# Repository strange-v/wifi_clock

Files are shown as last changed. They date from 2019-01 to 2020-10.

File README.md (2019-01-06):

# WiFi Clock
One more WiFi clock based on DS1339U and ESP8266. Requires 12V 1.5A power source.

## Functionality
* 24 hours time format
* Automatic time sync (NTP server and interval can be configured)
* Auto brightness
* DST support
* Display options (on/off leading zero, on/off column blinking, do not blink in a specific period of time)
* Over-the-Air update

## Main components
- ESP8266 - microcontroller 
- DS1339U - real time clock
- PCA9685 x 2 - LED controller
- BH1750FVI-TR - light sensor
- MT2492 - step-down  converter
- LM1117IMP-3.3 - voltage regulator

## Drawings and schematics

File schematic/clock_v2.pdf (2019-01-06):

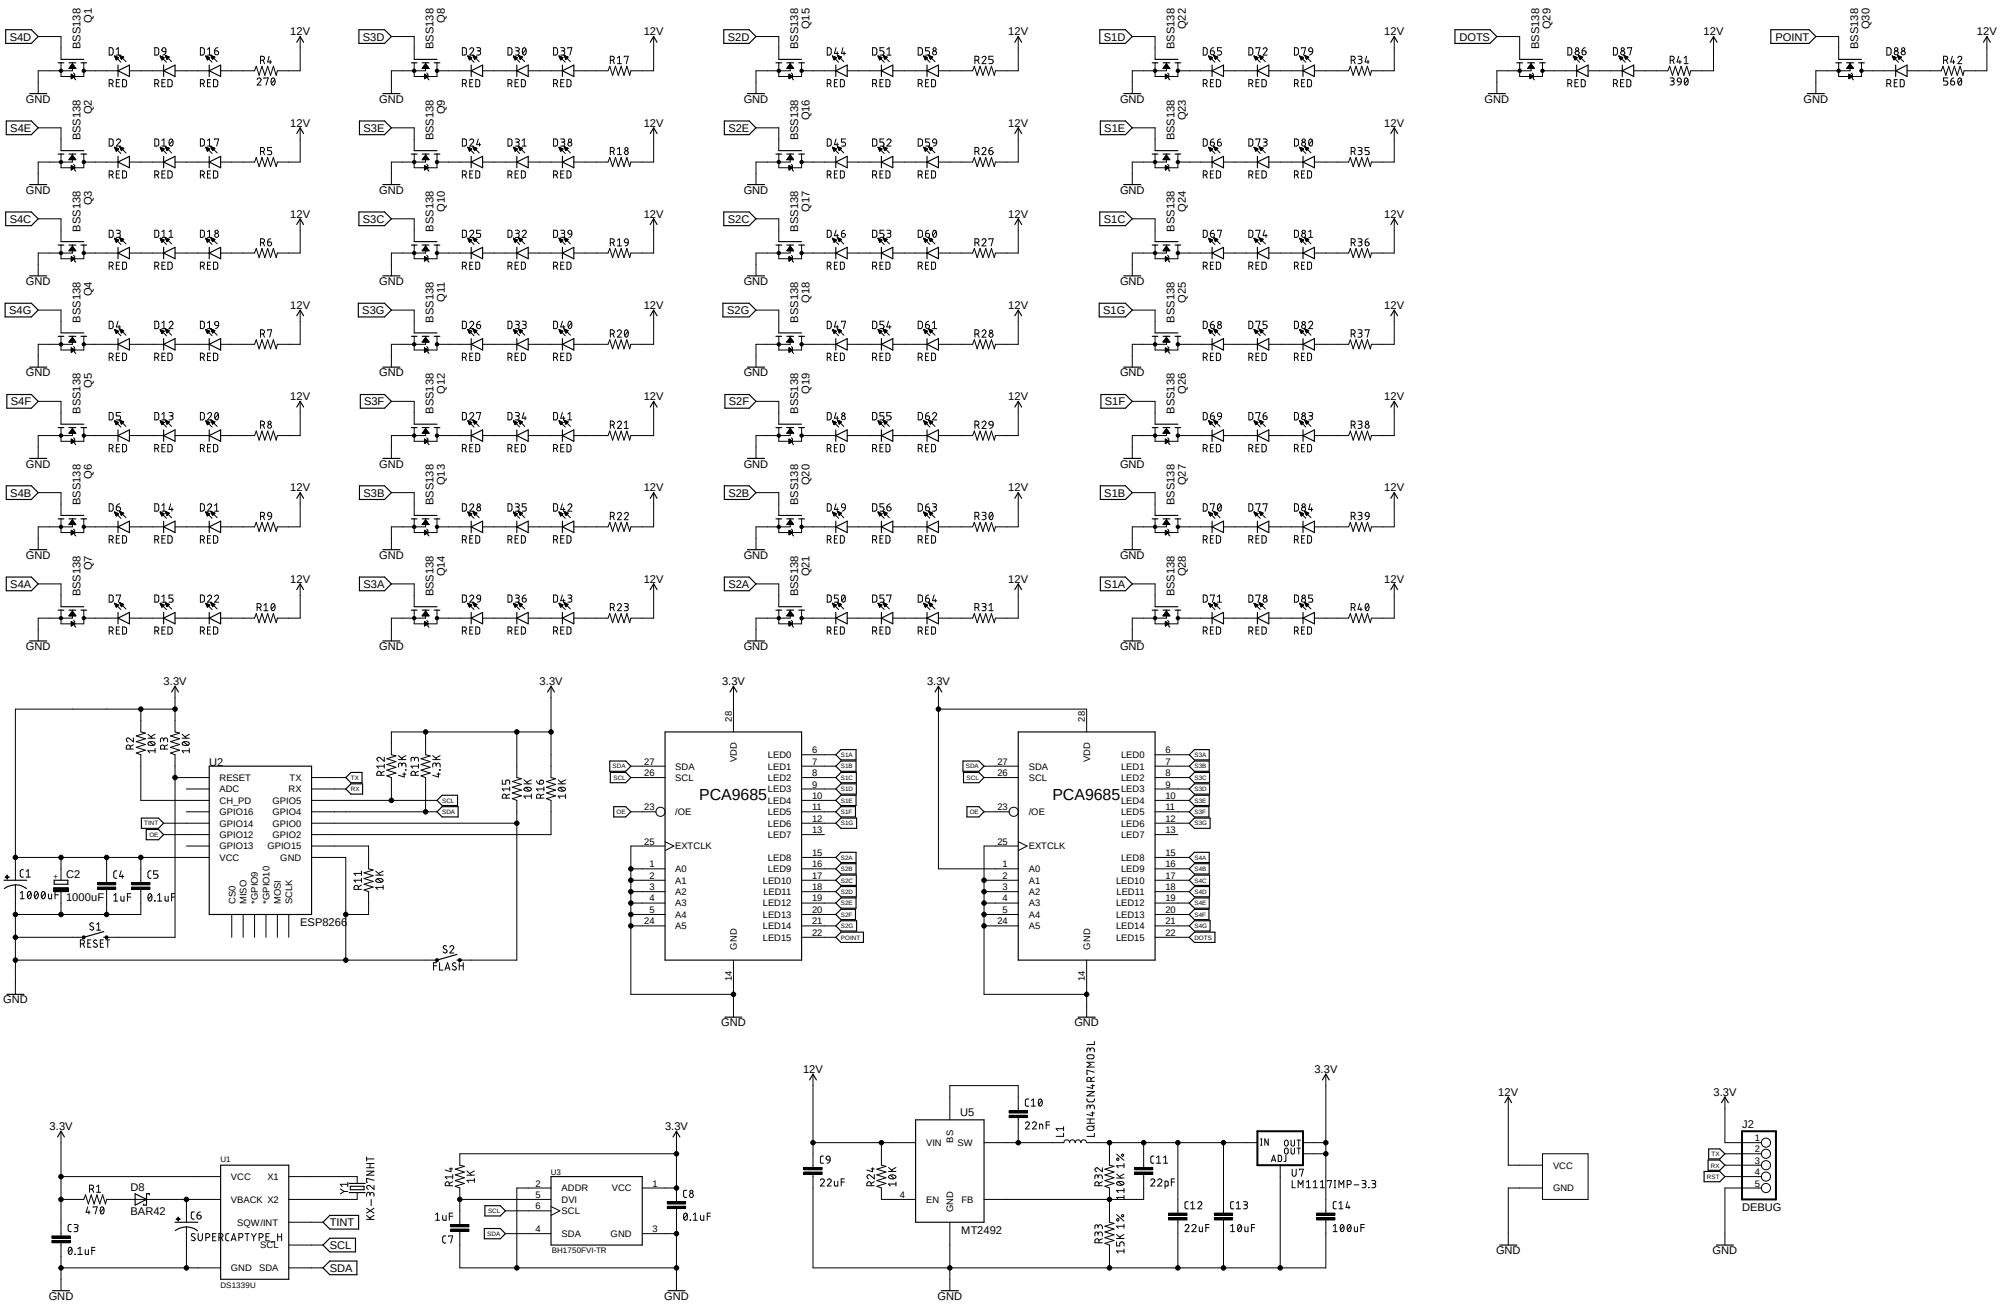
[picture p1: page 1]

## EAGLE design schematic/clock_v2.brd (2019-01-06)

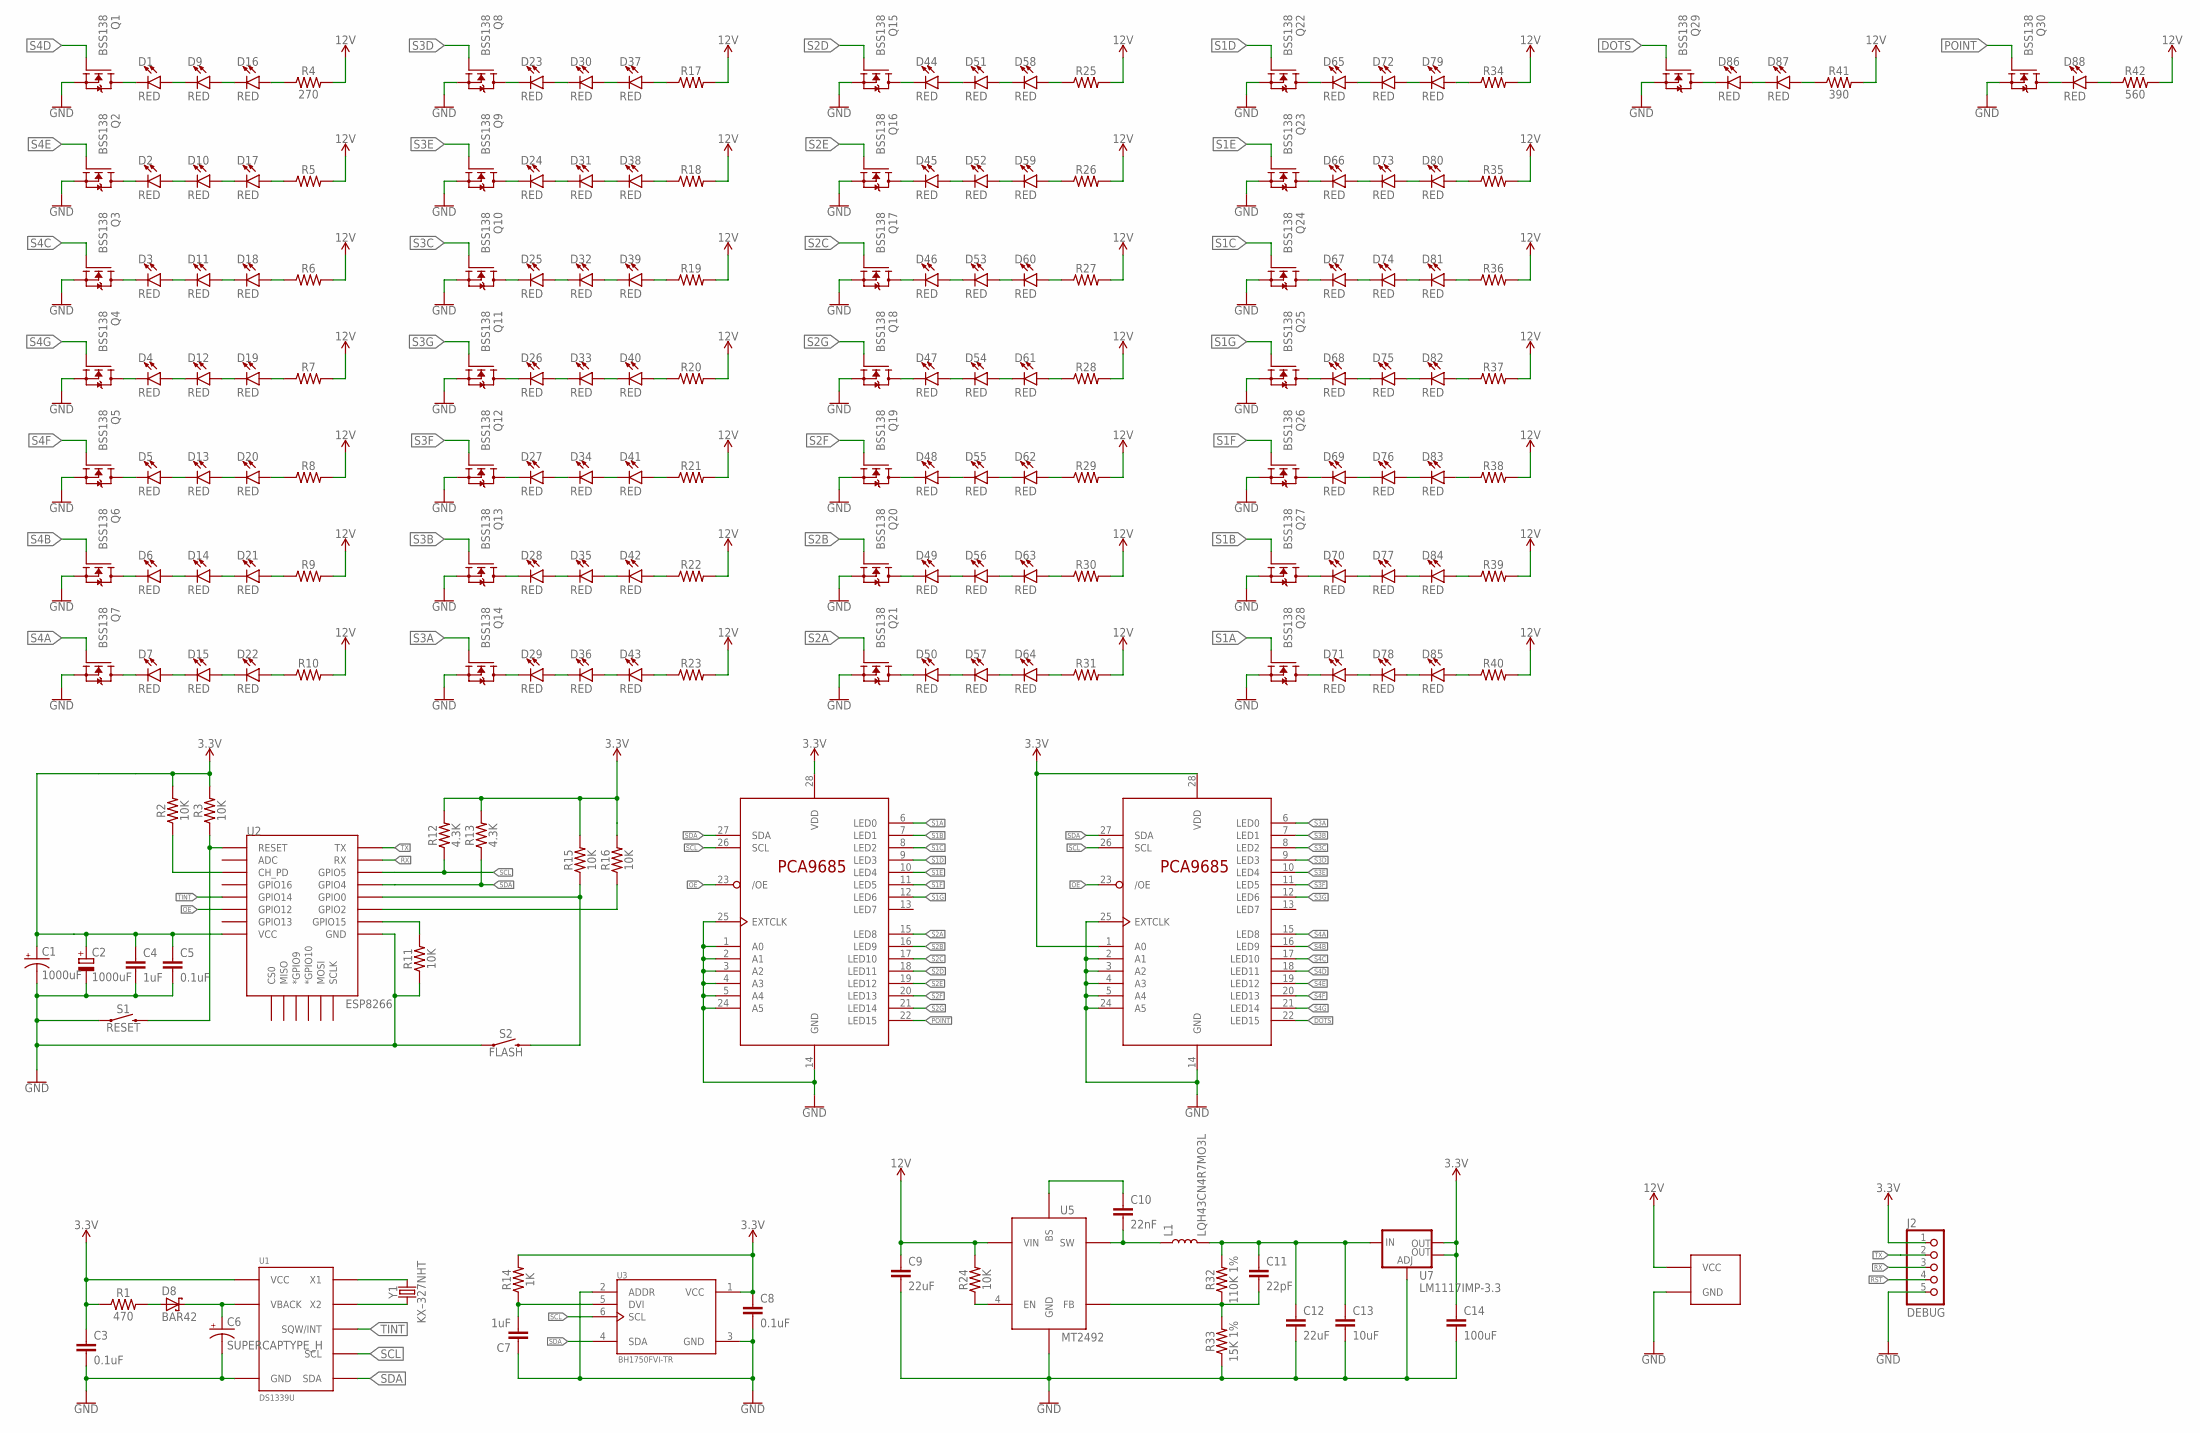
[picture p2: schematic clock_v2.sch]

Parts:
C1: 1000uF; CAP_8X11.5_P-3.5
C2: 1000uF; D/7343-31R
C3, C5, C8: 0.1uF; 1206
C4, C7: 1uF; 1206
C6: SUPERCAPTYPE_H; IONISTOR_TYPE_H
C9, C12: 22uF; 1206
C10: 22nF; 1206
C11: 22pF; 1206
C13: 10uF; 1206
C14: 100uF; C/6032-28R
D1, D2, D3, D4, D5, D6, D7, D9, D10, D11, D12, D13, D14, D15, D16, D17, D18, D19, D20, D21, D22, D23, D24, D25, D26, D27, D28, D29, D30, D31, D32, D33, D34, D35, D36, D37, D38, D39, D40, D41, D42, D43, D44, D45, D46, D47, D48, D49, D50, D51, D52, D53, D54, D55, D56, D57, D58, D59, D60, D61, D62, D63, D64, D65, D66, D67, D68, D69, D70, D71, D72, D73, D74, D75, D76, D77, D78, D79, D80, D81, D82, D83, D84, D85, D86, D87, D88: RED; LED-1206
D8: BAR42; SOT23
J1: POWER_SMD5.08; POWER_SMD_5.08
J2: DEBUG; ESP8266_DEBUG
L1: LQH43CN4R7MO3L; C1812
Q1, Q2, Q3, Q4, Q5, Q6, Q7, Q8, Q9, Q10, Q11, Q12, Q13, Q14, Q15, Q16, Q17, Q18, Q19, Q20, Q21, Q22, Q23, Q24, Q25, Q26, Q27, Q28, Q29, Q30: BSS138; SOT23
R1: 470; 1206
R2, R3, R11, R15, R16, R24: 10K; 1206
R4: 270; 1206
R5, R6, R7, R8, R9, R10, R17, R18, R19, R20, R21, R22, R23, R25, R26, R27, R28, R29, R30, R31, R34, R35, R36, R37, R38, R39, R40: 1206
R12, R13: 4.3K; 1206
R14: 1K; 1206
R32: 110K 1%; 1206
R33: 15K 1%; 1206
R41: 390; 1206
R42: 560; 1206
S1: RESET; TACTILE_SWITCH_SMD_5.2MM
S2: FLASH; TACTILE_SWITCH_SMD_5.2MM
U1: DS1339U
U2: ESP8266; ESP12E-SMD
U3: BH1750FVI-TR; SOTFL50P300X75-6N
U4, U6: PCA9685PW; TSSOP28
U5: MT2492; SOT23-6
U7: LM1117IMP-3.3; SOT223
Y1: KX–327NHT; QSMD3.2X1.5

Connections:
3.3V: C1.+, C2.+, C3.1, C4.1, C5.1, C8.1, C14.+ (1), J2.1, R1.1, R2.2, R3.2, R12.2, R13.2, R14.2, R15.2, R16.2, U1.8 (VCC), U2.VCC, U3.1 (VCC), U4.28 (VDD), U6.1 (A0), U6.28 (VDD), U7.2 (OUT), U7.4 (OUT)
12V: C9.1, J1.VCC, R4.2, R5.2, R6.2, R7.2, R8.2, R9.2, R10.2, R17.2, R18.2, R19.2, R20.2, R21.2, R22.2, R23.2, R24.2, R25.2, R26.2, R27.2, R28.2, R29.2, R30.2, R31.2, R34.2, R35.2, R36.2, R37.2, R38.2, R39.2, R40.2, R41.2, R42.2, U5.5 (VIN)
DOTS: Q29.1 (G), U6.22 (LED15)
FLASH: R15.1, S2.3 (2), S2.4 (2), U2.GPIO0
GND: C1.-, C2.-, C3.2, C4.2, C5.2, C6.GND (-), C7.1, C8.2, C9.2, C12.2, C13.2, C14.- (2), J1.GND, J2.5, Q1.2 (S), Q2.2 (S), Q3.2 (S), Q4.2 (S), Q5.2 (S), Q6.2 (S), Q7.2 (S), Q8.2 (S), Q9.2 (S), Q10.2 (S), Q11.2 (S), Q12.2 (S), Q13.2 (S), Q14.2 (S), Q15.2 (S), Q16.2 (S), Q17.2 (S), Q18.2 (S), Q19.2 (S), Q20.2 (S), Q21.2 (S), Q22.2 (S), Q23.2 (S), Q24.2 (S), Q25.2 (S), Q26.2 (S), Q27.2 (S), Q28.2 (S), Q29.2 (S), Q30.2 (S), R11.1, R33.1, S1.1, S1.2 (1), S2.1, S2.2 (1), U1.4 (GND), U2.GND, U3.2 (ADDR), U3.3 (GND), U4.1 (A0), U4.2 (A1), U4.3 (A2), U4.4 (A3), U4.5 (A4), U4.14 (GND), U4.24 (A5), U4.25 (EXTCLK), U5.2 (GND), U6.2 (A1), U6.3 (A2), U6.4 (A3), U6.5 (A4), U6.14 (GND), U6.24 (A5), U6.25 (EXTCLK), U7.1 (ADJ)
unnamed: D1.C, Q1.3 (D)
unnamed: D1.A, D9.C
unnamed: D2.C, Q2.3 (D)
unnamed: D2.A, D10.C
unnamed: D3.C, Q3.3 (D)
unnamed: D3.A, D11.C
unnamed: D11.A, D18.C
unnamed: D18.A, R6.1
unnamed: D4.C, Q4.3 (D)
unnamed: D4.A, D12.C
unnamed: D12.A, D19.C
unnamed: D19.A, R7.1
unnamed: D7.C, Q7.3 (D)
unnamed: D7.A, D15.C
unnamed: D50.C, Q21.3 (D)
unnamed: D23.C, Q8.3 (D)
unnamed: D23.A, D30.C
unnamed: D30.A, D37.C
unnamed: D37.A, R17.1
unnamed: D24.C, Q9.3 (D)
unnamed: D24.A, D31.C
unnamed: D31.A, D38.C
unnamed: D38.A, R18.1
unnamed: D25.C, Q10.3 (D)
unnamed: D25.A, D32.C
unnamed: D32.A, D39.C
unnamed: D39.A, R19.1
unnamed: D27.C, Q12.3 (D)
unnamed: D50.A, D57.C
unnamed: D57.A, D64.C
unnamed: D49.C, Q20.3 (D)
unnamed: D49.A, D56.C
unnamed: D56.A, D63.C
unnamed: D48.C, Q19.3 (D)
unnamed: D48.A, D55.C
unnamed: D55.A, D62.C
unnamed: D47.C, Q18.3 (D)
unnamed: D47.A, D54.C
unnamed: D54.A, D61.C
unnamed: D46.C, Q17.3 (D)
unnamed: D46.A, D53.C
unnamed: D53.A, D60.C
unnamed: D44.C, Q15.3 (D)
unnamed: D44.A, D51.C
unnamed: D51.A, D58.C
unnamed: D52.A, D59.C
unnamed: D45.A, D52.C
unnamed: D45.C, Q16.3 (D)
unnamed: D64.A, R31.1
unnamed: D63.A, R30.1
unnamed: D62.A, R29.1
unnamed: D61.A, R28.1
unnamed: D60.A, R27.1
unnamed: D59.A, R26.1
unnamed: D58.A, R25.1
unnamed: D65.C, Q22.3 (D)
unnamed: D86.A, D87.C
unnamed: D86.C, Q29.3 (D)
unnamed: D9.A, D16.C
unnamed: D16.A, R4.1
unnamed: D10.A, D17.C
unnamed: D17.A, R5.1
unnamed: D15.A, D22.C
unnamed: D22.A, R10.1
unnamed: D6.C, Q6.3 (D)
unnamed: D6.A, D14.C
unnamed: D14.A, D21.C
unnamed: D21.A, R9.1
unnamed: D5.C, Q5.3 (D)
unnamed: D5.A, D13.C
unnamed: D13.A, D20.C
unnamed: D20.A, R8.1
unnamed: D88.C, Q30.3 (D)
unnamed: D27.A, D34.C
unnamed: D87.A, R41.1
unnamed: D88.A, R42.1
unnamed: D34.A, D41.C
unnamed: D41.A, R21.1
unnamed: D28.C, Q13.3 (D)
unnamed: D28.A, D35.C
unnamed: D35.A, D42.C
unnamed: D42.A, R22.1
unnamed: D29.C, Q14.3 (D)
unnamed: D29.A, D36.C
unnamed: D36.A, D43.C
unnamed: D43.A, R23.1
unnamed: D26.C, Q11.3 (D)
unnamed: D26.A, D33.C
unnamed: D33.A, D40.C
unnamed: D40.A, R20.1
unnamed: D65.A, D72.C
unnamed: D72.A, D79.C
unnamed: D79.A, R34.1
unnamed: D66.C, Q23.3 (D)
unnamed: D66.A, D73.C
unnamed: D73.A, D80.C
unnamed: D80.A, R35.1
unnamed: D67.C, Q24.3 (D)
unnamed: D67.A, D74.C
unnamed: D74.A, D81.C
unnamed: D81.A, R36.1
unnamed: D82.A, R37.1
unnamed: D75.A, D82.C
unnamed: D68.A, D75.C
unnamed: D68.C, Q25.3 (D)
unnamed: D69.C, Q26.3 (D)
unnamed: D69.A, D76.C
unnamed: D76.A, D83.C
unnamed: D83.A, R38.1
unnamed: D84.A, R39.1
unnamed: D77.A, D84.C
unnamed: D70.A, D77.C
unnamed: D70.C, Q27.3 (D)
unnamed: D71.C, Q28.3 (D)
unnamed: D71.A, D78.C
unnamed: D78.A, D85.C
unnamed: D85.A, R40.1
unnamed: C6.VCC (+), D8.3 (C), U1.3 (VBACK)
unnamed: C7.2, R14.1, U3.5 (DVI)
unnamed: D8.1 (A), R1.2
unnamed: U1.1 (X1), Y1.2
unnamed: U1.2 (X2), Y1.1
unnamed: R11.2, U2.GPIO15
unnamed: R2.1, U2.CH_PD
unnamed: R16.1, U2.GPIO2
unnamed: R24.1, U5.4 (EN)
unnamed: C10.1, U5.1 (BS)
unnamed: C10.2, L1.1, U5.6 (SW)
unnamed: C11.1, C12.1, C13.1, L1.2, R32.2, U7.3 (IN)
unnamed: C11.2, R32.1, R33.2, U5.3 (FB)
OE: U2.GPIO12, U4.23 (/OE), U6.23 (/OE)
POINT: Q30.1 (G), U4.22 (LED15)
RST: J2.4, R3.1, S1.3 (2), S1.4 (2), U2.RESET
RX: J2.3, U2.RXD0 (RX)
S1A: Q28.1 (G), U4.6 (LED0)
S1B: Q27.1 (G), U4.7 (LED1)
S1C: Q24.1 (G), U4.8 (LED2)
S1D: Q22.1 (G), U4.9 (LED3)
S1E: Q23.1 (G), U4.10 (LED4)
S1F: Q26.1 (G), U4.11 (LED5)
S1G: Q25.1 (G), U4.12 (LED6)
S2A: Q21.1 (G), U4.15 (LED8)
S2B: Q20.1 (G), U4.16 (LED9)
S2C: Q17.1 (G), U4.17 (LED10)
S2D: Q15.1 (G), U4.18 (LED11)
S2E: Q16.1 (G), U4.19 (LED12)
S2F: Q19.1 (G), U4.20 (LED13)
S2G: Q18.1 (G), U4.21 (LED14)
S3A: Q14.1 (G), U6.6 (LED0)
S3B: Q13.1 (G), U6.7 (LED1)
S3C: Q10.1 (G), U6.8 (LED2)
S3D: Q8.1 (G), U6.9 (LED3)
S3E: Q9.1 (G), U6.10 (LED4)
S3F: Q12.1 (G), U6.11 (LED5)
S3G: Q11.1 (G), U6.12 (LED6)
S4A: Q7.1 (G), U6.15 (LED8)
S4B: Q6.1 (G), U6.16 (LED9)
S4C: Q3.1 (G), U6.17 (LED10)
S4D: Q1.1 (G), U6.18 (LED11)
S4E: Q2.1 (G), U6.19 (LED12)
S4F: Q5.1 (G), U6.20 (LED13)
S4G: Q4.1 (G), U6.21 (LED14)
SCL: R12.1, U1.6 (SCL), U2.GPIO5, U3.6 (SCL), U4.26 (SCL), U6.26 (SCL)
SDA: R13.1, U1.5 (SDA), U2.GPIO4, U3.4 (SDA), U4.27 (SDA), U6.27 (SDA)
TINT: U1.7 (SQW/INT), U2.GPIO14
TX: J2.2, U2.TXD0 (TX)

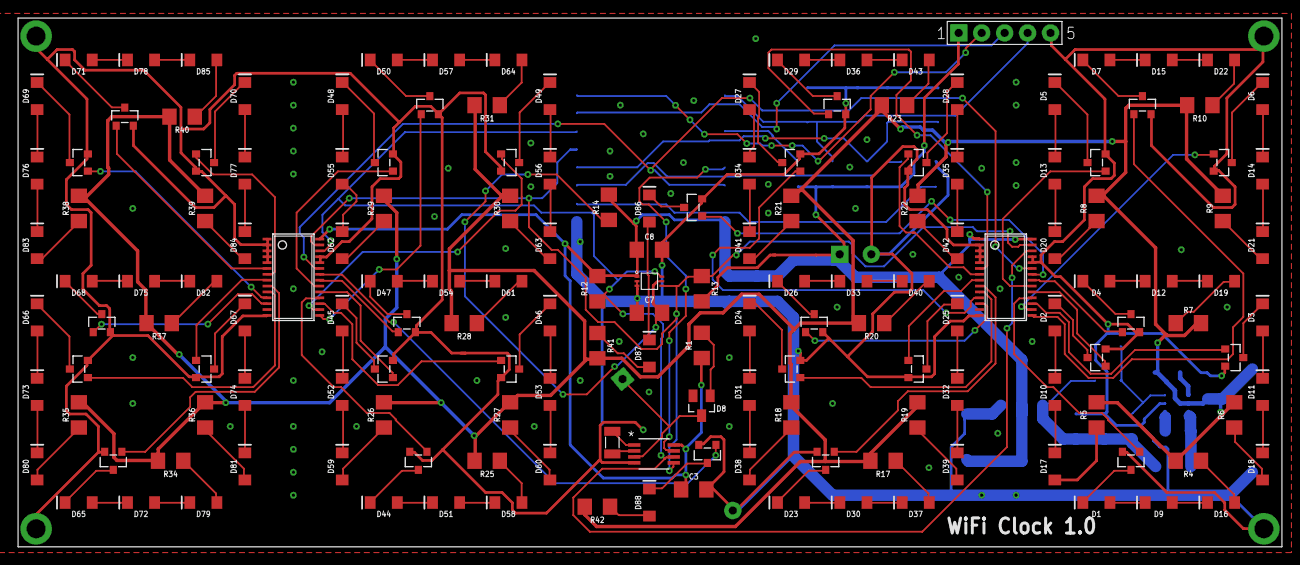
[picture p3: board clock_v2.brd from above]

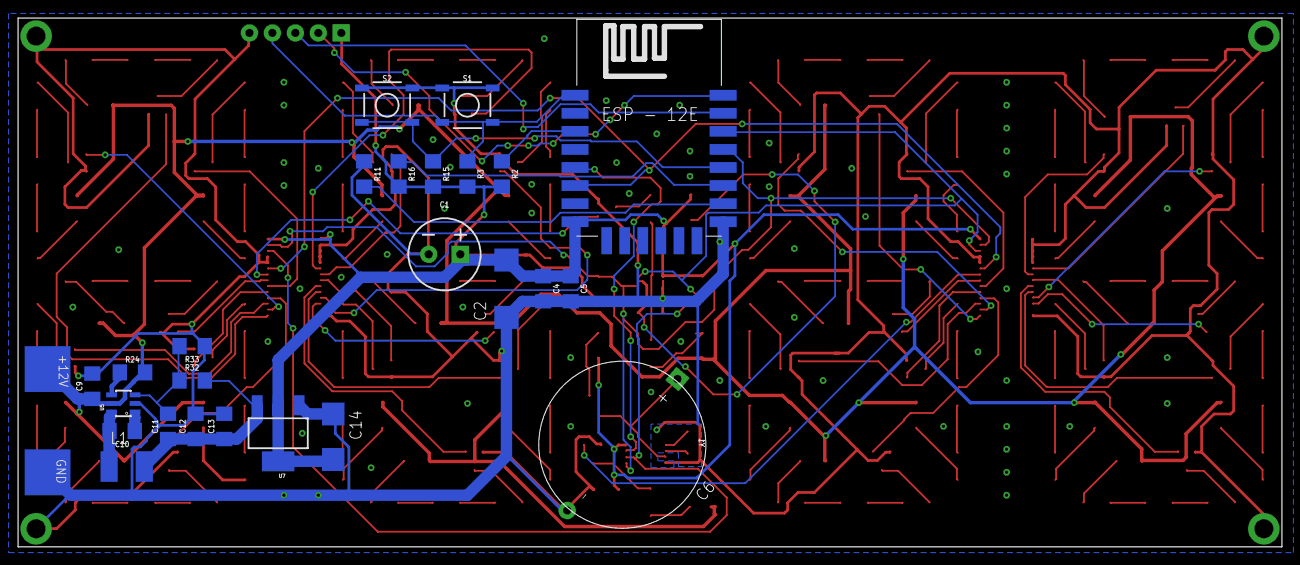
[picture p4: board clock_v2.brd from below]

Board: 2 copper layers, 139.9 x 58.5 mm, 187 parts (26 on the bottom side), 171 nets.

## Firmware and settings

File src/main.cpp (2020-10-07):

#include <Arduino.h>
#include <ArduinoOTA.h>
#include <ESP8266WiFi.h>
#include <WiFiUdp.h>
#include <FS.h>
#include <Task.h>
#include <NTPClient.h>
#include <Wire.h>
#include <BH1750.h>
#include <RtcDS3231.h>
#include <Timezone.h>
#include <Adafruit_PWMServoDriver.h>
#include <ESP8266WebServer.h>
#include <ArduinoJson.h>
#include "ClockMode.h"
#include "SettingsHelper.h"
#include "Cfg.h"
#include "Led.h"
#include "NetworkFunctionality.h"
#include "DisplayFunctionality.h"
#include "WebServerFunctionality.h"

TaskManager taskManager;
FunctionTask taskCheckConnection(_checkConnection, MsToTaskTime(5 * 1000));
FunctionTask taskTurnOfNetwork(_turnOfNetwork, MsToTaskTime(2 * 60 * 1000));
FunctionTask taskDelayedSyncTime(_delayedSyncTime, MsToTaskTime(15 * 1000));
FunctionTask taskScheduledSyncTime(_scheduledSyncTime, MsToTaskTime(5 * 60 * 60 * 1000ul));

WiFiEventHandler ehNetworkConnected, ehNetworkDisconnected;
WiFiUDP ntpUDP;
NTPClient timeClient(ntpUDP);
BH1750 lightMeter;
RtcDS3231<TwoWire> Rtc(Wire);
Led led(&Wire, Cfg::pinOe);
Timezone *timezone;
ESP8266WebServer server(80);

Settings *_cfg;
ConnectionState _connectionState = CS_DISCONNECTED;
ClockMode _clockMode = CM_LOADING;
bool _isRtcOk = false;
unsigned long _connectionStart = 0;
volatile byte _rtcPinState = LOW;
volatile byte _updateDisplay = 0;
uint32_t _lastTimeSync = 0;
unsigned long _testTime = 0;

void setup()
{
	Serial.begin(115200);
#ifdef CL_DEBUG
	delay(3000);
	printModuleInfo();
#endif

	pinMode(Cfg::pinOe, OUTPUT);
	pinMode(Cfg::pinRtcInt, INPUT_PULLUP);

	WiFi.persistent(false);
	WiFi.mode(WIFI_STA);
	SPIFFS.begin();

	SettingsHelper::init(256);
	_cfg = SettingsHelper::get();

	ArduinoOTA.setPassword(_cfg->otaPwd);
	ArduinoOTA.begin();

	Wire.begin(Cfg::pinSda, Cfg::pinScl);
	Wire.setClock(400000);

	led.begin();

	bool lightMeterState = lightMeter.begin();
#ifdef CL_DEBUG
	if (lightMeterState)
		Serial.println(F("BH1750 initialized"));
	else
		Serial.println(F("Error initialising BH1750"));
#endif

	Rtc.Begin();
	Rtc.SetSquareWavePin(DS3231SquareWavePin_ModeClock);
	Rtc.SetSquareWavePinClockFrequency(DS3231SquareWaveClock_1Hz);
	if (Rtc.IsDateTimeValid() && Rtc.GetIsRunning())
	{
		_isRtcOk = true;
		_clockMode = CM_CLOCK;
	}
	else
	{
		if (!Rtc.IsDateTimeValid())
		{
#ifdef CL_DEBUG
			Serial.println(F("RTC lost confidence in the DateTime!"));
#endif
			Rtc.SetDateTime(0);
		}

		if (!Rtc.GetIsRunning())
		{
#ifdef CL_DEBUG
			Serial.println(F("RTC was not actively running, starting now"));
#endif
			Rtc.SetIsRunning(true);
		}
	}

	timezone = new Timezone(_cfg->startDST, _cfg->endDST);
	timeClient.begin();
	timeClient.setPoolServerName(_cfg->ntpUrl);

	taskScheduledSyncTime.setTimeInterval(_cfg->syncPeriod * 60 * 1000ul);
	taskManager.StartTask(&taskScheduledSyncTime);

	attachInterrupt(digitalPinToInterrupt(Cfg::pinRtcInt), rtcInterrupt, CHANGE);

	connectToNetwork(true);
}

void printDateTime(const RtcDateTime &dt)
{
	char datestring[20];

	snprintf_P(datestring,
			   sizeof(datestring) / sizeof(datestring[0]),
			   PSTR("%02u/%02u/%04u %02u:%02u:%02u"),
			   dt.Month(),
			   dt.Day(),
			   dt.Year(),
			   dt.Hour(),
			   dt.Minute(),
			   dt.Second());
	Serial.print(datestring);
}

void loop()
{
	ArduinoOTA.handle();
	yield();
	taskManager.Loop();
	yield();
	server.handleClient();
	yield();

	if (_updateDisplay > 0)
	{
		_updateDisplay--;
		updateDisplay();
	}
#ifdef CL_DEBUG
	unsigned long ms = millis();
	if (ms - _testTime > 10000 || ms < _testTime)
	{
		_testTime = ms;

		uint16_t lux = lightMeter.readLightLevel();
		Serial.print("Light: ");
		Serial.print(lux);
		Serial.println(" lx");

		RtcDateTime now = Rtc.GetDateTime();
		printDateTime(now);
		Serial.println();
	}
#endif
}

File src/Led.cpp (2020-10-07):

#include "Led.h"

Led::Led(TwoWire *wire, byte pinOe)
{
	_pwm1 = new Adafruit_PWMServoDriver(&Wire, 0x40);
	_pwm2 = new Adafruit_PWMServoDriver(&Wire, 0x41);
	_pinOe = pinOe;
}

Led::~Led()
{
	delete _pwm1;
	delete _pwm2;
}

void Led::begin()
{
	_pwm1->begin();
	_pwm2->begin();

	_pwm1->reset();
	_pwm2->reset();

	_pwm1->setPWMFreq(1600);
	_pwm2->setPWMFreq(1600);

	digitalWrite(_pinOe, LOW);

	//ToDo: implement clear display
	showDot(false);
	showColumn(false);
}

void Led::showTime(RtcDateTime time, bool leadingZero)
{
	_showDigit(time.Hour() < 10 && !leadingZero ? 10 : time.Hour() / 10, 0);
	_showDigit(time.Hour() % 10, 1);
	_showDigit(time.Minute() / 10, 2);
	_showDigit(time.Minute() % 10, 3);
}

void Led::showSsid(byte id)
{
	_showDigit(12, 0);
	_showDigit(13, 1);
	_showDigit(id / 10, 2);
	_showDigit(id % 10, 3);
}

void Led::showColumn(bool show)
{
	_showColumn(show);
}

void Led::showDot(bool show)
{
	_showDot(show);
}

void Led::setPWM(uint16_t value)
{
	if (_pwmValue == value)
		return;

	_pwmValue = value;

	_showDigit(_digit[0], 0, true);
	_showDigit(_digit[1], 1, true);
	_showDigit(_digit[2], 2, true);
	_showDigit(_digit[3], 3, true);

	_showDot(_dotState, true);
	_showColumn(_columnState, true);
}

void Led::_showDigit(byte value, byte position, bool force)
{
	if (value > 13)
		value = 11;

	if (_digit[position] == value && !force)
		return;

	_digit[position] = value;
	Adafruit_PWMServoDriver *pwm = position > 1 ? _pwm2 : _pwm1;
	byte idx = position % 2 == 0 ? 0 : 8;

	for (size_t i = 0; i < 7; i++)
	{
		bool show = digitMap[value][i] == 1;
		pwm->setPin(i + idx, show ? _pwmValue : 0);
	}
}

void Led::_showColumn(bool show, bool force)
{
	if (_columnState == show && !force)
		return;

	_columnState = show;
	_pwm2->setPin(15, show ? _pwmValue : 0);
}

void Led::_showDot(bool show, bool force)
{
	if (_dotState == show && !force)
		return;

	_dotState = show;
	_pwm1->setPin(15, show ? _pwmValue : 0);
}

void Led::spin()
{
	for (byte p = 0; p < 4; p++)
	{
		Adafruit_PWMServoDriver *pwm = p > 1 ? _pwm2 : _pwm1;
		byte idx = p % 2 == 0 ? 0 : 8;
		for (size_t i = 0; i < 7; i++)
		{
			bool show = spinMap[_idx][p] == i;
			pwm->setPin(i + idx, show ? _pwmValue : 0);
		}
	}

	_idx++;
	if (_idx > 5)
		_idx = 0;
}

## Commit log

2018-10-15 Improved Network functions, introduced Led class, TimeSync functionality
2018-10-16 Fixed time sync issue, added time displaying, timezones
    [DisplayFunctionality.cpp, Led.cpp]
2018-10-17 Fixed incorrect time displaying (zero related), refactoring
    [DisplayFunctionality.cpp, Led.cpp]
2018-10-18 Moved SimpleTime struct to a separate file, fixed overload methods
    [DisplayFunctionality.cpp]
2018-10-20 Added web server functionality, refactored: - SimpleTime - added loading and displaying wifi SSID - Led class
2018-10-21 Integrated simple lux to PWM mapping Fixed bug in SettingsHelper Improved API path
    [DisplayFunctionality.cpp, NetworkFunctionality.cpp, WebServerFunctionality.cpp]
2018-10-29 Improved JSON parsing, fixed time bug
    [DisplayFunctionality.cpp, NetworkFunctionality.cpp, WebServerFunctionality.cpp]
2019-01-06 Added schematic, updated readme
    [clock_v2.brd, clock_v2.sch]
2020-03-14 Implemented correct offset support Bug-fix: Start web server after AP initialized. Migrated project to PIO. Updated UI files.
    [Cfg.h, DisplayFunctionality.cpp, NetworkFunctionality.cpp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]
2020-10-07 Moved project to PIO, fixed incorrect start with no WiFi
    [Cfg.h, DisplayFunctionality.cpp, Led.cpp]

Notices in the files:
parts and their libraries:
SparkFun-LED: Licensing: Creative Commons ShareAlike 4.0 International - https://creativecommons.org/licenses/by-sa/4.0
